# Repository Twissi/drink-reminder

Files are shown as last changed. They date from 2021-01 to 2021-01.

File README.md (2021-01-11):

# Water drink reminder

When sitting on the desk all day i tend to forget to drink water.

This projects visually reminds me to drink more water and also shows the progress I make throught the day to reach my drinking goal.

Stay hydrated! 💦 💦

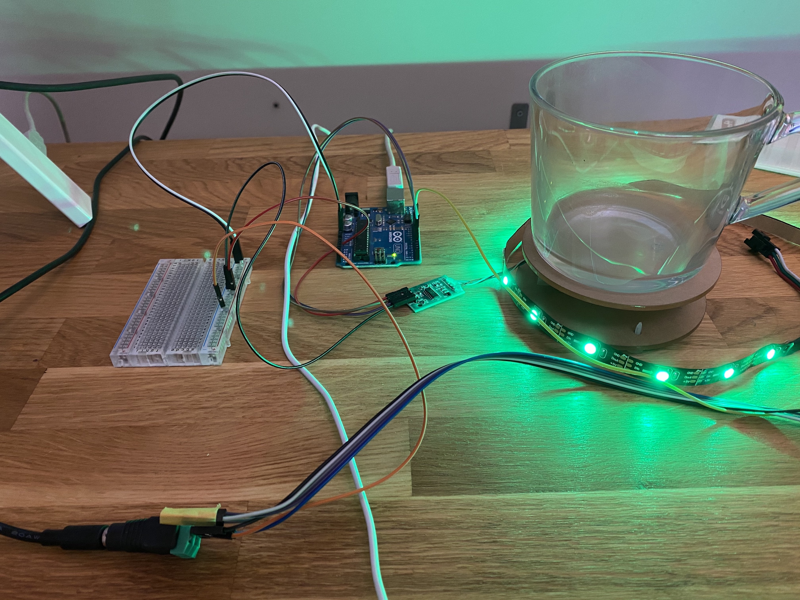
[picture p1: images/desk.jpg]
Desk


## Parts list

- Arduino Uno
- Neopixel Strip
- HX711 Weighing Sensor Module with load cell
- 300Ω - 500Ω Resistor

- 5V Power Source
- USB Cable
- BreadBoard
- Jump Wires

## Parts images

| Name | Image |
| --- | --- |
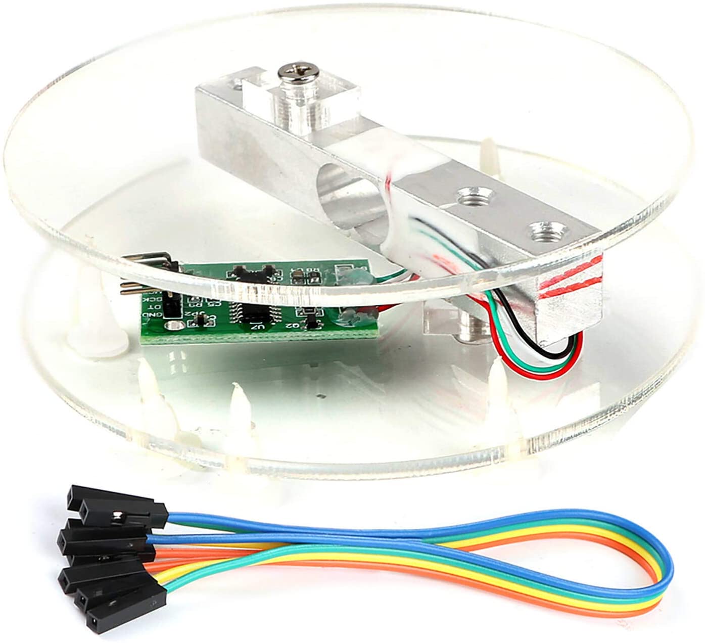
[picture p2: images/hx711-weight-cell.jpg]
Weight cell
| HX711 Weighing Sensor Module with load cell |  |

## Libraries

HX711_ADC: https://github.com/olkal/HX711_ADC

Adafruit_NeoPixel: https://github.com/adafruit/Adafruit_NeoPixel

## Wiring

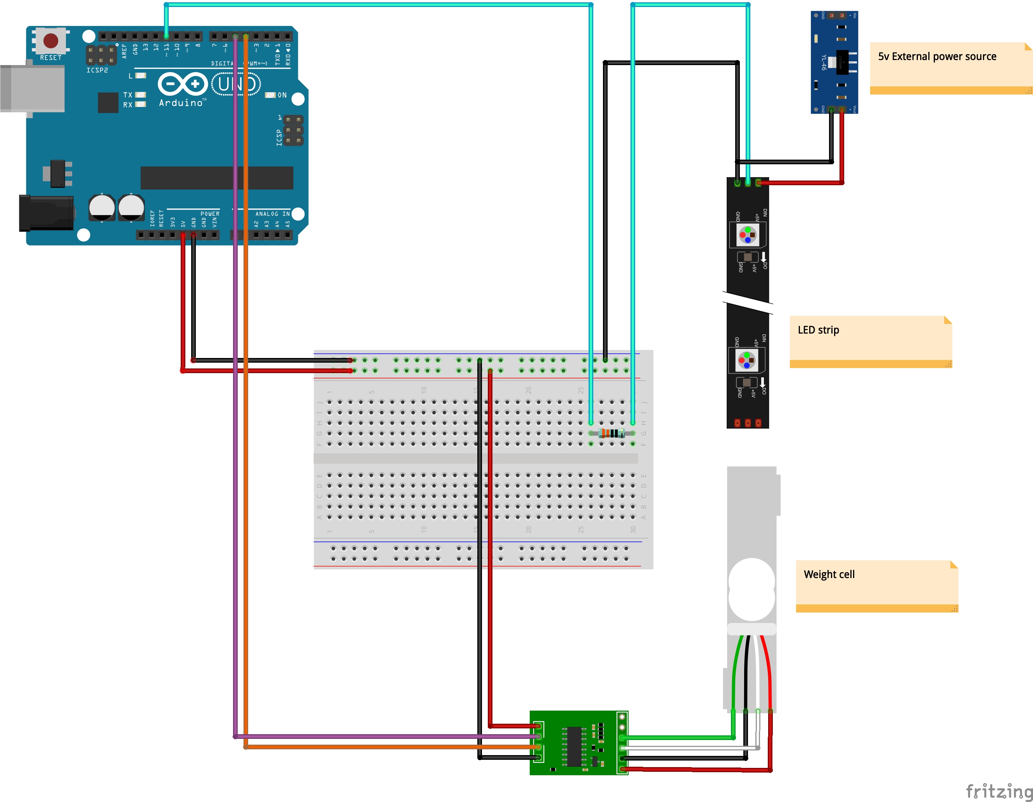
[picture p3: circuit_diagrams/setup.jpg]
Setup


## Weight cell calibration

Please follow the calibration from the example file `Calibration.ino` of [HX711 lib](https://github.com/olkal/HX711_ADC/blob/master/examples/Calibration/Calibration.ino).

## Configuration

In the `drink-reminder.ino` you need to configure the following values:

Make sure the pins match with your setup:

- HX711_dout = 4; (HX711 dout pin)
- HX711_sck = 5; (HX711 sck pin)
- LEDSTRIP_pin = 11; (led strip data pin)

Update the following variables:

- LEDS_COUNT = 15; (count of the leds you led strip has)
- REMINDER_INTERVAL = 600000; (10 min reminder interval)
- WATERMAX_ML = 2000; (2000 ml drink target)
- WEIGHT_CALIBRATION_VALUE = 385.46; (load cell calibration value)

## Usage

1. Connect the Arduino via USB to your computer
2. Connect the Ledstrip to the external power source
3. Before starting the program remove the glas from the weight
4. Upload the sketch file to your Arduino
5. The led will blink in red during the startup phase
6. After the led shows red (without blinking), put on the glas filled with water
7. When removing or adding the glass the led will blink purple (measuring)
8. Use the glass normally. Refill when needed
9. When putting the glas back on the weight the leds will show your progress (you start with one green led and you reached your goal when all leds are green)
10. Each day you need to restart the program in order to start with total water amount of 0

## Color coding

**Blinking red led**: Starting up

**Red led**: Glas is missing

**Blinking purple led**: Measurement in progress

**Blinking blue leds**: Drink reminder!

**Green led**: Number of leds show drink progress towards your goal

## FAQ

> How do i restart the program?

You can use the reset button on the Arduino.

> Do i need to subtract the weight of my glas?

No, the weight of the glas does not matter. Although you should not use glasses with different weights throughout a day.

> Can i power the ledstrip and the weight sensor module throught the same Arduino?

Yes, you can. But i run into issues with the weight changing when turning LEDs on vs. off. Thats why i switched to power the ledstrip with an external power source.

> Do i need the resistor for the led strip?

I don't use it but it's recommended by Adafruit: https://learn.adafruit.com/adafruit-neopixel-uberguide/best-practices

> Are you missing a capacitor for the led strip?

You are probably right. A capacitor is recommended by Adafruit: https://learn.adafruit.com/adafruit-neopixel-uberguide/best-practices

> The weight cell amount is slowly increasing throughout the day

I see the same issue. Starting with 0.09 the weight of the empty load cell increases throughout the day. Not sure why.

## ToDos

- [ ] 3d print a case
- [ ] transition setup and code to a smaller board
- [ ] move all components + leds into the case

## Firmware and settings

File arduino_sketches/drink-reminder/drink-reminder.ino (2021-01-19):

/*
   -------------------------------------------------------------------------------------
   Drink reminder

   Uses the following libraries:
   Arduino library for HX711 24-Bit Analog-to-Digital Converter for Weight Scales
   Arduino library for Adafruit Neopixel
   -------------------------------------------------------------------------------------
*/

/*
   Before uploading the program calibrate the weight and update the WEIGHT_CALIBRATION_VALUE
   
   Before starting the program remove the glas from the weight
   After the led shows red, put on the glas filled with water
   Each day you need to restart the program in order to start with 0 total water amount

   Color coding:
   Blinking red led: Starting up
   Red led: glas is missing
   Blinking purple led: measurement in progress
   Blinking blue leds: Drink reminder!
   Green led: Number of LEDs show drink progress towards your goal
*/

#ifdef __AVR__
#include <avr/power.h>
#endif

#include <HX711_ADC.h>
#include <EEPROM.h>
#include <Adafruit_NeoPixel.h>

// pins:
const int HX711_dout = 4; //mcu > HX711 dout pin
const int HX711_sck = 5; //mcu > HX711 sck pin
const int LEDSTRIP_pin = 11; // led strip data pin

// configuration
const int LEDS_COUNT = 15;
const long REMINDER_INTERVAL = 600000; //10 min reminder interval
const int WATERMAX_ML = 2000; //2000 ml drink target
const float WEIGHT_CALIBRATION_VALUE = 385.46; //calibration value (see example file "Calibration.ino" of HX711 lib)

// logs:
const bool LOG_WEIGHT = 0;
const bool LOG_UNSTABLE_MEASUREMENT = 0;
const bool LOG_TOTAL_AMOUNT_PIXEL = 0;
const bool LOG_LAST_WEIGHT = 0;

// HX711 constructor:
HX711_ADC LoadCell(HX711_dout, HX711_sck);

// NeoPixel constructor:
Adafruit_NeoPixel strip = Adafruit_NeoPixel(LEDS_COUNT, LEDSTRIP_pin, NEO_GRB + NEO_KHZ800);


// Global variables
long prevTime;
float totalWaterAmount = 0;
bool isLoaded = 0;
bool prevIsLoaded = 0;
float lastWeightLoaded;
float lastWeightMeasurement = 0;
long lastReminderMillis = 0;
uint32_t savedLedColors[LEDS_COUNT];

void setup() {
  Serial.begin(57600); delay(10);
  Serial.println();
  Serial.println("Starting...");

  // strip setup
  strip.begin();
  displayBlinkingColor(strip.Color(255, 0, 0), 50); // Red blinking lights

  LoadCell.begin();
  float calibrationValue = WEIGHT_CALIBRATION_VALUE;
  long stabilizingtime = 2000; // preciscion right after power-up can be improved by adding a few seconds of stabilizing time
  boolean _tare = true; //set this to false if you don't want tare to be performed in the next step
  LoadCell.start(stabilizingtime, _tare);
  if (LoadCell.getTareTimeoutFlag()) {
    Serial.println("Timeout, check MCU>HX711 wiring and pin designations");
    while (1);
  }
  else {
    LoadCell.setCalFactor(calibrationValue); // set calibration value (float)
    Serial.println("Startup is complete");
    displayColor(strip.Color(255, 0, 0), 0); // Red light
  }
}

void loop() {
  static boolean newDataReady = 0;
  const int serialPrintInterval = 0; // increase value to slow down serial print activity

  // check for new data/start next conversion:
  if (LoadCell.update()) newDataReady = true;

  // get smoothed value from the dataset
  if (newDataReady) {
    if (millis() > prevTime + serialPrintInterval) {
      float i = LoadCell.getData();
      // action to be done after new weight was measured
      onNewWeight(i);
      newDataReady = 0;
      prevTime = millis();
    }
  }

  // drink reminder
  if (millis() >= lastReminderMillis + REMINDER_INTERVAL) {
    Serial.println("Don't forget to drink water!");
    lastReminderMillis = millis();
    saveLedColors();
    displayBlinkingColor(strip.Color(0, 0, 127), 50); // Blue blinking lights
    resetLedColors();
  }
}

// On weight cell load - new weight found
void onNewWeight(float weight) {
  if (LOG_WEIGHT) {
    Serial.print("Current weight: ");
    Serial.println(weight);
  }

  if (!isStableValue(weight)) {
    return;
  }

  if (weight < 100.00) {
    isLoaded = 0;
  } else {
    isLoaded = 1;
  }


  // detect state change (glas was put on)
  if (isLoaded != prevIsLoaded) {
    prevIsLoaded = isLoaded;

    if (isLoaded) {
      if (LOG_LAST_WEIGHT) {
        Serial.print("Last onload weight: ");
        Serial.println(lastWeightLoaded);
      }
      
      if (!lastWeightLoaded) {
        lastWeightLoaded = weight;
        displayColor(strip.Color(0, 255, 0), 50); // Green lights = glas found, no prev weight found
        displayWhite();
        return;
      }
      // check if water decreased
      if (lastWeightLoaded > weight + 1.00) {
        totalWaterAmount = totalWaterAmount + lastWeightLoaded - weight;
        // reset reminder
        lastReminderMillis = millis();
        Serial.print("Good job, water decreased! Your drank in total:");
        Serial.println(totalWaterAmount);
      }

      lastWeightLoaded = weight;  
      
      displayTotalWaterAmount(strip.Color(0, 255, 0), 50); // Green lights = glas found, show total amount
    } else {
      displayColor(strip.Color(255, 0, 0), 0); // Red lights = glas missing
    }
  }
}

// return if weight is stable or not
bool isStableValue(float weight) {
  if (abs(lastWeightMeasurement) + 0.20 > abs(weight) && abs(lastWeightMeasurement) - 0.20 < abs(weight)) {
    lastWeightMeasurement = weight;
    return true;
  }

  if (LOG_UNSTABLE_MEASUREMENT) {
    Serial.println("Unstable measurement, please wait!");
  }
  displayColor(strip.Color(255, 0, 213), 10); // Blue blinking lights
  displayWhite();
  lastWeightMeasurement = weight;
  return false;
}

// save led color
void saveLedColors() {
  for (uint16_t i = 0; i < strip.numPixels(); i++) {
    savedLedColors[i] = strip.getPixelColor(i);
  }
}

// set led strip to saved led color
void resetLedColors() {
  for (uint16_t i = 0; i < strip.numPixels(); i++) {
    strip.setPixelColor(i, savedLedColors[i]);
    strip.show();
  }
}

void displayWhite() {
  displayColor(strip.Color(0, 0, 0, 255), 0); // White
}

// LEDStrip animation: Fill the dots one after the other with a color
void displayColor(uint32_t c, uint8_t wait) {
  for (uint16_t i = 0; i < strip.numPixels(); i++) {
    strip.setPixelColor(i, c);
    strip.show();
    delay(wait);
  }
}

// LEDStrip animation: Only fill as many dots mapping the totalWaterAmount in percent
void displayTotalWaterAmount(uint32_t c, uint8_t wait) {
  int amountPerPixel = floor(WATERMAX_ML / strip.numPixels());
  int numberOfPixels = ceil(totalWaterAmount / amountPerPixel);

  if (numberOfPixels > strip.numPixels()) {
    numberOfPixels = strip.numPixels();
  }
  if (LOG_TOTAL_AMOUNT_PIXEL) {
    Serial.print("Show total amount pixel(s): ");
    Serial.println(numberOfPixels);
  }

  for (uint16_t i = 0; i < numberOfPixels; i++) {
    strip.setPixelColor(i, c);
    strip.show();
    delay(wait);
  }
}

// LEDStrip animation: Theatre-style crawling lights.
void displayBlinkingColor(uint32_t c, uint8_t wait) {
  for (int j = 0; j < 10; j++) { //do 10 cycles of chasing
    for (int q = 0; q < 3; q++) {
      for (uint16_t i = 0; i < strip.numPixels(); i = i + 3) {
        strip.setPixelColor(i + q, c);  //turn every third pixel on
      }
      strip.show();

      delay(wait);

      for (uint16_t i = 0; i < strip.numPixels(); i = i + 3) {
        strip.setPixelColor(i + q, 0);      //turn every third pixel off
      }
    }
  }
}

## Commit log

2021-01-09 Add documentation
    [setup.fzz]
2021-01-17 Fix save strip color after reminder shows
    [drink-reminder.ino]
